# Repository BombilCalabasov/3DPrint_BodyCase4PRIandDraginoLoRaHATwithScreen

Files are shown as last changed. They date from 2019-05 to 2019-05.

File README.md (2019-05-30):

# 3DPrint_BodyCase4PRIandDraginoLoRaHATwithScreen
Files for 3D print the BodyCase for assembled RaspberryPI3 + Dragino LoRa Hat + 5" 800x480 DSI Screen

<p>There is the project for 3D print the case for assembled device from next components:</p>
<ol><li>Raspberry Pi2/3/3+</li>
<li><a href="http://www.dragino.com/products/lora/item/106-lora-gps-hat.html">Dragino LoRa&GPS Hat for Raspberry Pi</a></li>
<li><a href="https://www.aliexpress.com/item/32954192404.html?spm=a2g0s.8937460.0.0.66932e0eVrc0Jg">5 inch 800x480 TFT Touch Screen LCD Display with DSI Connector for Raspberry Pi</a></li></ol>

<p>This assembled device is very useful for any tests of LoRa technology but it's so fragile and can be damaged very easy.</p>
<p>
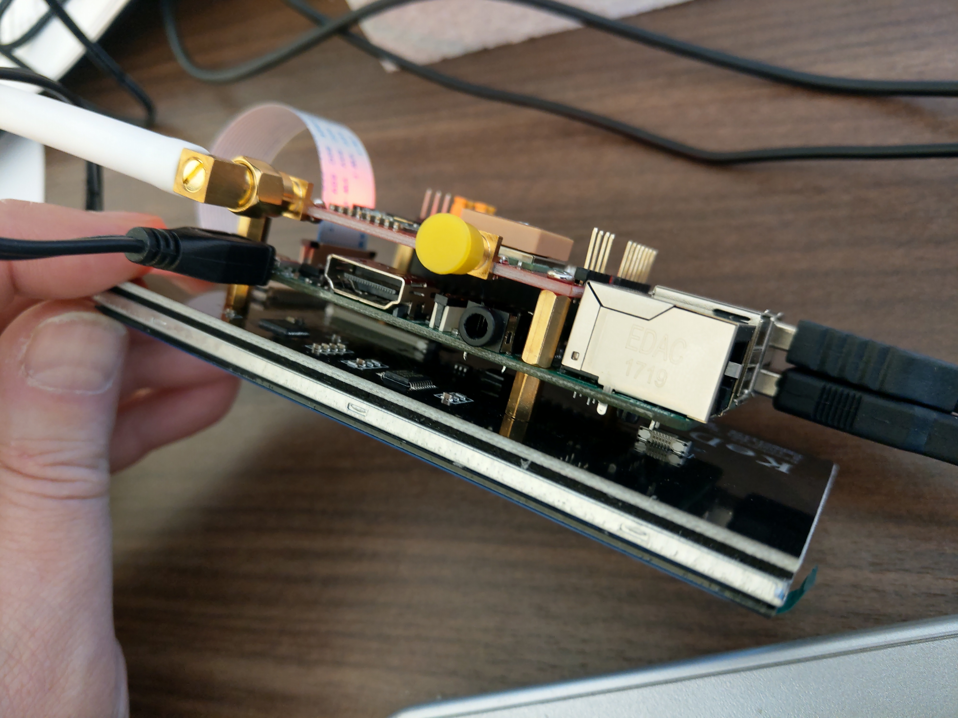
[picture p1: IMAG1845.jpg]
</br>
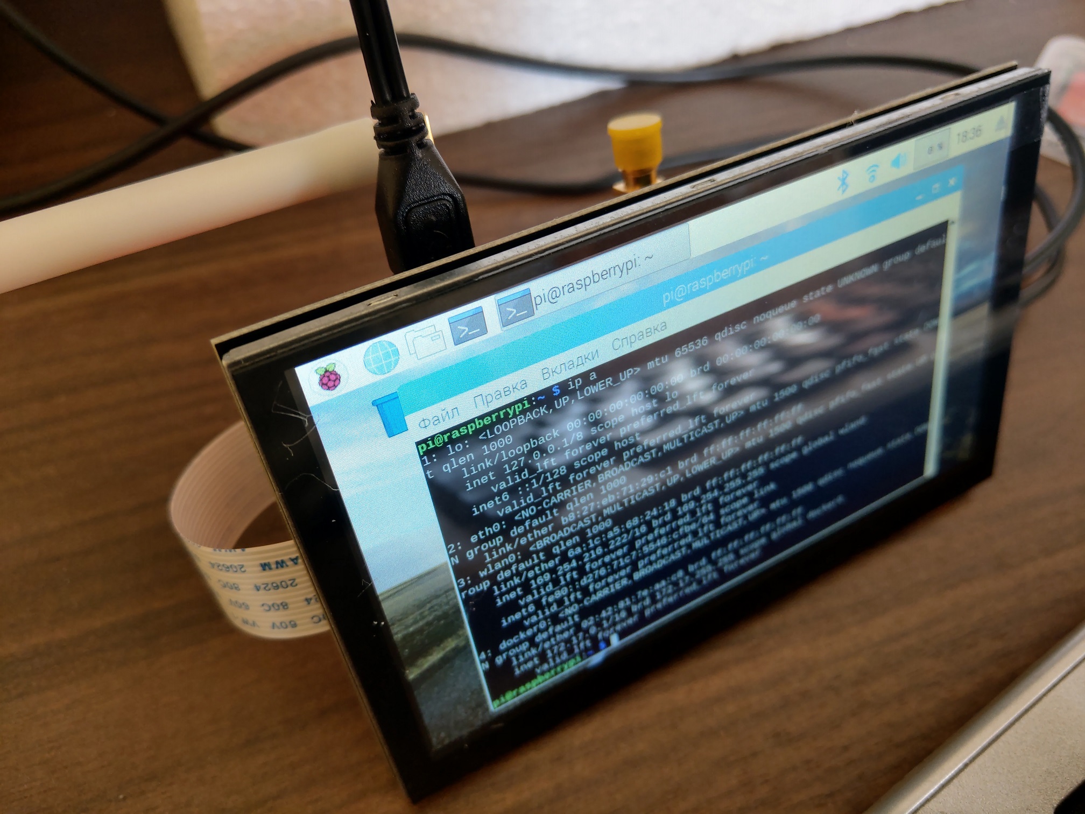
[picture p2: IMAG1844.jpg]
</br>
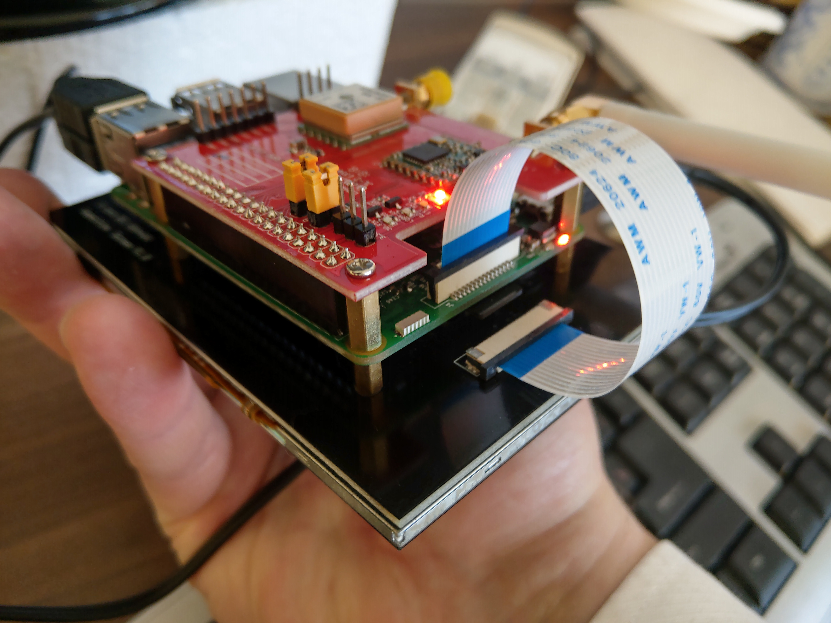
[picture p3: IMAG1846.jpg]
</br>
</p>
<h2>Modifying GPIO Connector at Dragino board</h2>
<p>First of all the Dragino board was modifyed to allow connect any additional HW (sensors and modules) to Raspberry GPIO connector without Body Case disassembling. The <a href="https://www.aliexpress.com/item/32898319378.html?spm=a2g0s.9042311.0.0.6f554c4du8pb8R">40-pins 'PC-104'-type connector</a> was used for replace original Dragino connector.</br>(N.B. Of course, you must have a good experience in soldering and proper tools to change the connector without damaging the board.)</p><p>
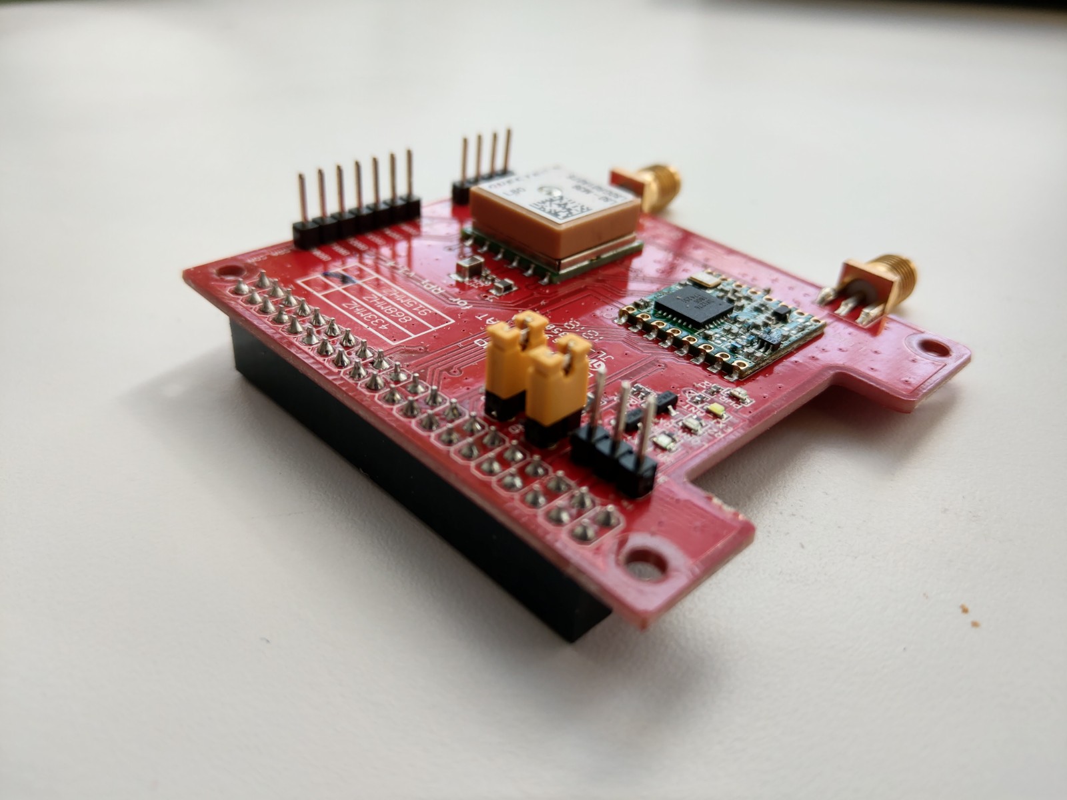
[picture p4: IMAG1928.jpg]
Original Dragino Hat</img></br></br>
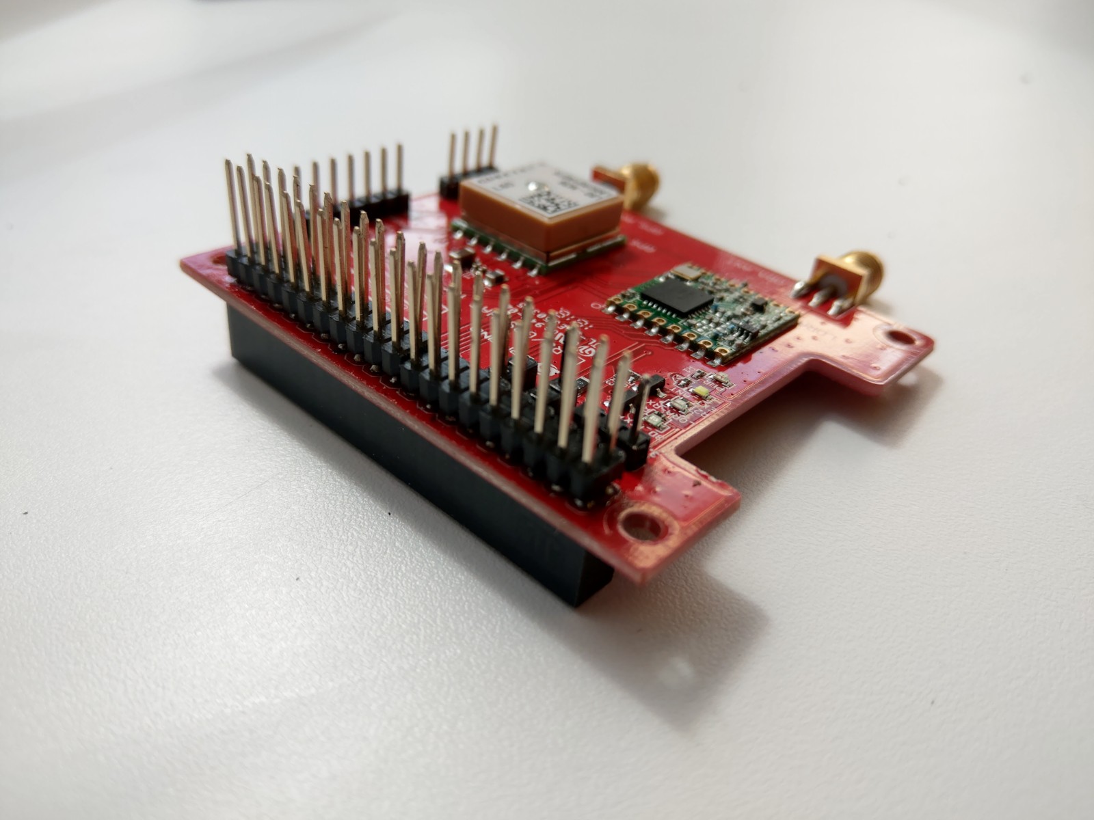
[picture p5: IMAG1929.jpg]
Modifyed Dragino Hat</img></br></br>
</p>
<h2>3D-printable Body Case</h2>
<p>To prevent possible damaging the 3D-printable case was deployed.  It contents three parts:</p>
<ol>
<li>Front panel (screen cover) -- <a href="RPi3wScreen-FrontPanel.stl">.STL</a>, <a href="RPi3wScreen-FrontPanel.zip">.OBJ(ZIP)</a></li>
<li>Body -- <a href="./PRi3wScreen-Body.stl">.STL</a>, <a href="./PRi3wScreen-Body.zip">.OBJ(ZIP)</a></li>
<li>Hat cover -- <a href="./PRi3wScreen-Hat2.stl">.STL</a>, <a href="PRi3wScreen-Hat2.zip">.OBJ(ZIP)</a></li></ol>

<h2>How to assemble</h2><ol>
  <li>Put the Screen into printed Front Panel.</li>
  <li>Install printed Body part of case. Use any four small 2mm screws to fix the Body part at Front panel.</li>
  <li>Connect DSI interface to Display.</li>
  <li>Install previously prepared SD card into SD-slot at Raspberry.</li>
  <li>Install Raspberry into Body and fix it by brass cylinders from Dragino pack.</li>
  <li>Connect DSI interface to Raspberry.</li>
  <li>Install Dragino LoRa&GPS HAT at Raspberry and fix it by four screws.</li>
  <li>Close the body of case by Hat Cover and fix it by others four small screw.</li></ol>
<p>Now your accembled device is ready for tests.</p>
<p>
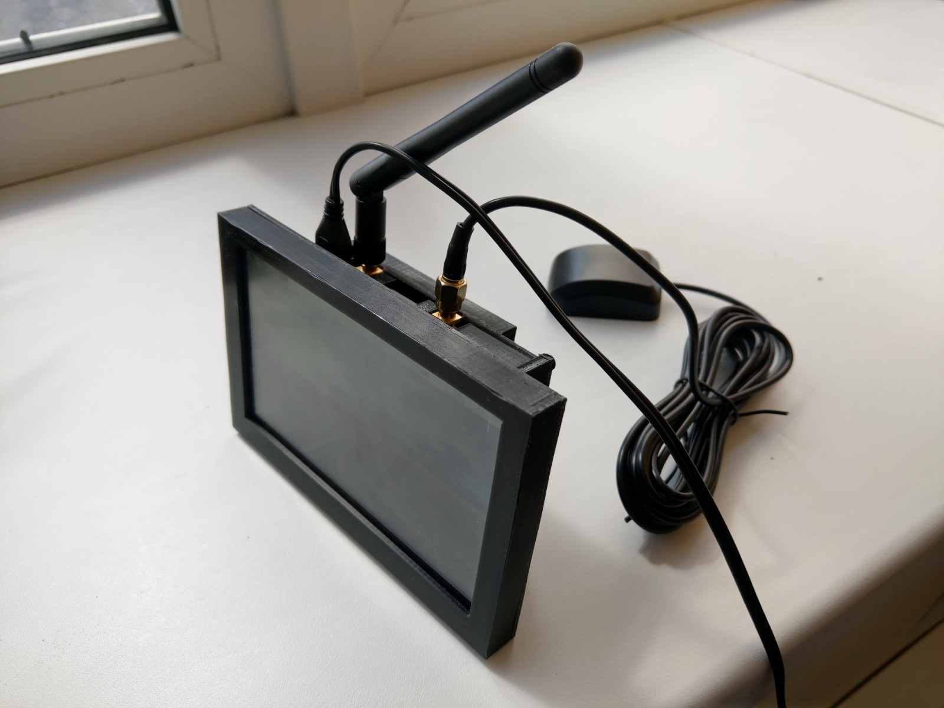
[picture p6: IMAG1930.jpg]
Assembled device</img></br></br>
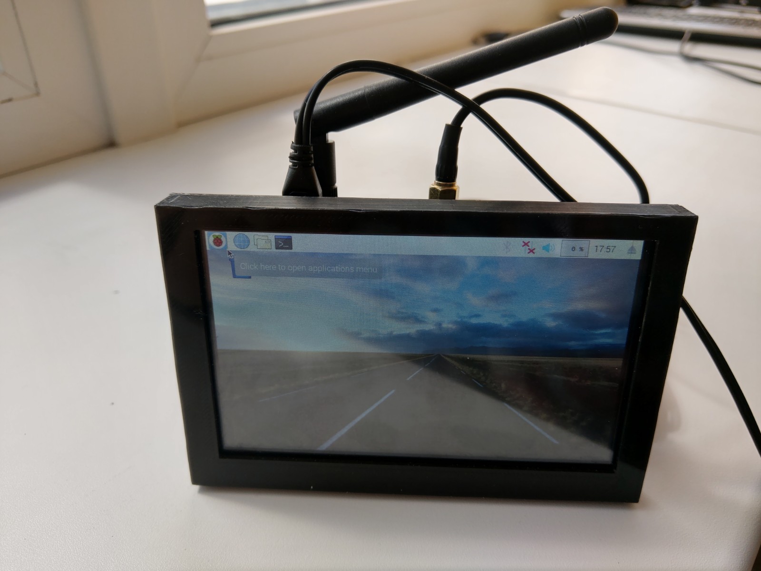
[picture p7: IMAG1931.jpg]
</br></br>
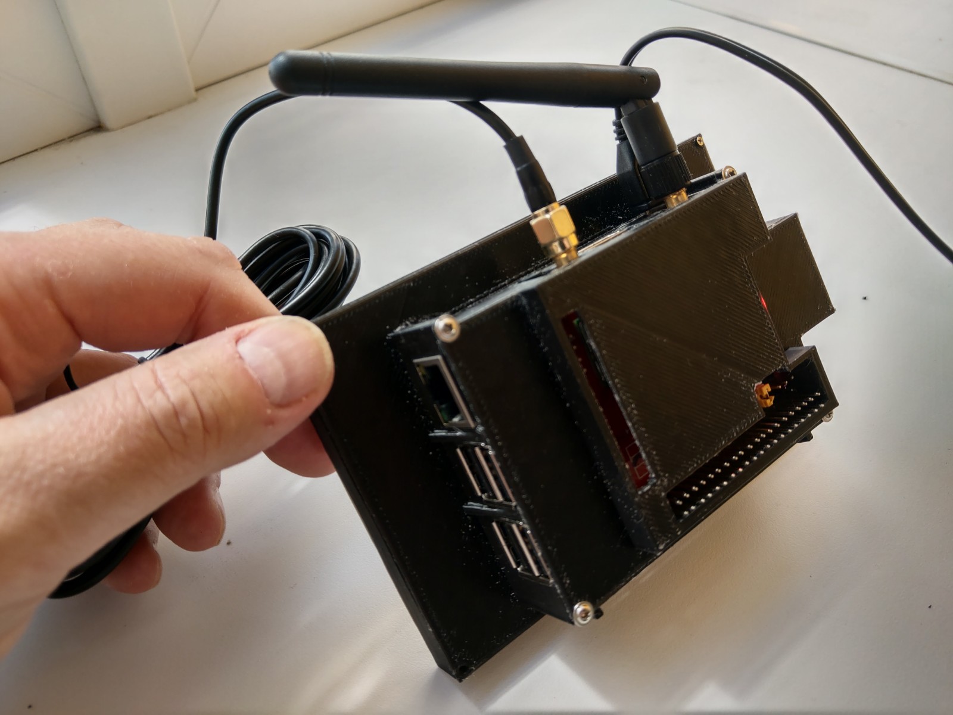
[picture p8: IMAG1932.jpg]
</br></br>
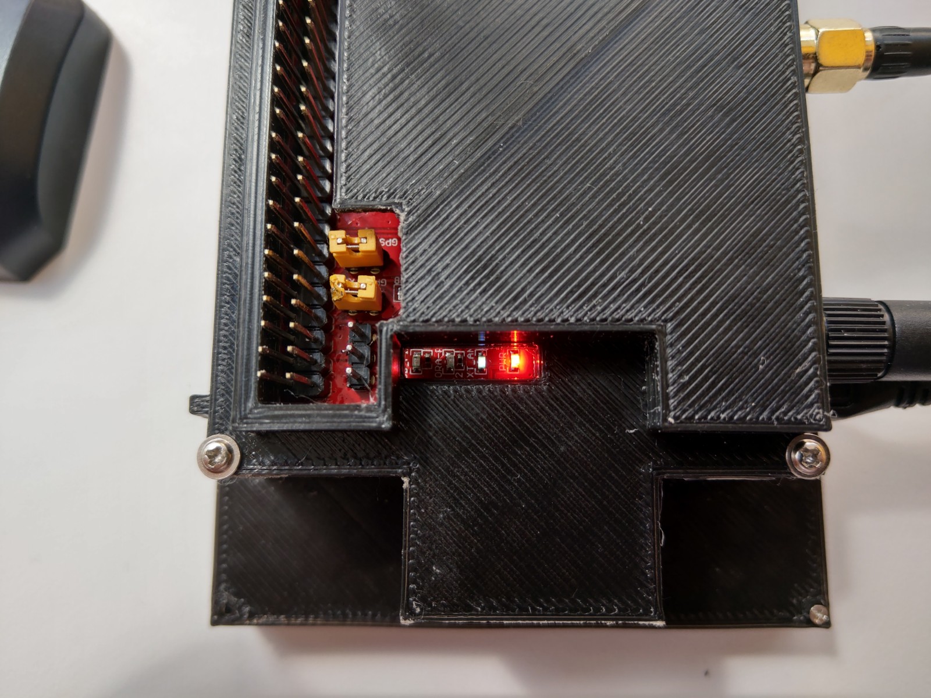
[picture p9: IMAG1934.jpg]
The Body Case has small windows for LEDs at Dragino and Raspberry boards.</img></br></br>
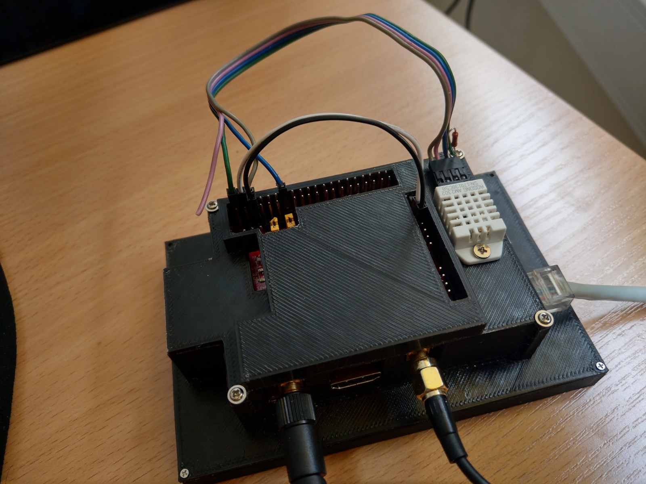
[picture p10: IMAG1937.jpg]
With this case you can easy connect any additional sensors - DHT-22 for example.</img></p>
<h2>PRO & CONS</h2>
<h3>PRO</h3>
<ul>
  <li>You can easy connect any additional sensors and modules directly to Raspberry GPIO Connector and Dragino HAT pins without disassembling Body Case.</li>
  <li>The Body Case has special holes at the bottom for air cooling. Anyway using any special radiators for Raspberry CPU is the good idea.</li>
  <li>The Body Case has special small windows to look at the LEDs state - both on Dragino and Raspberry boards.</li>
</ul>
<h3>CONS</h3><ul>
  <li>The changing the SD-card is very hard procedure with this Body Case because DSI cable covers SD-slot. To change SD-card you will be able to partially disassemble this device to grant the access to SD-card slot. Sorry, but I have no ideas how to solve this issue.</li>
  <li>Used 40pins 'PC-104' connector has the too long pins. They slightly protrude from the body cover. It's has a risk of short sircuit and damage the device. In my case it's not important because all tests are peroformed at my desktop. If this issue is important for you try to find another item with shorten pins.</li></ul>

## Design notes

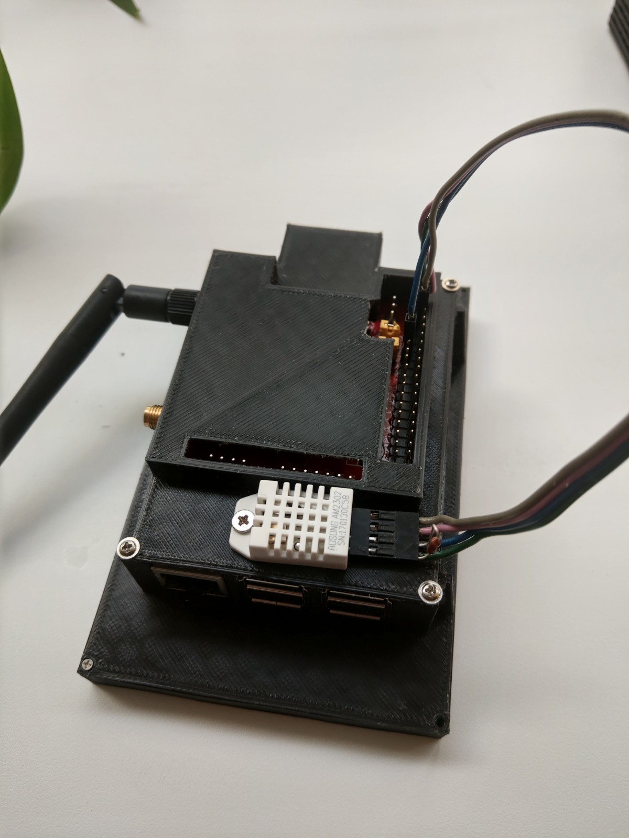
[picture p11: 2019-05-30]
IMAG1936.jpg

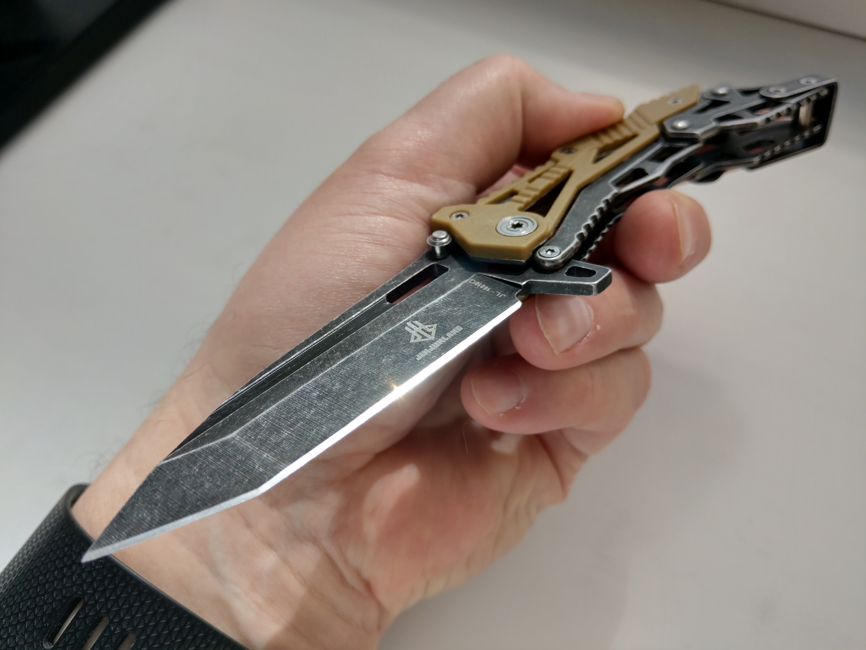
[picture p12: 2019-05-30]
IMAG1848.jpg

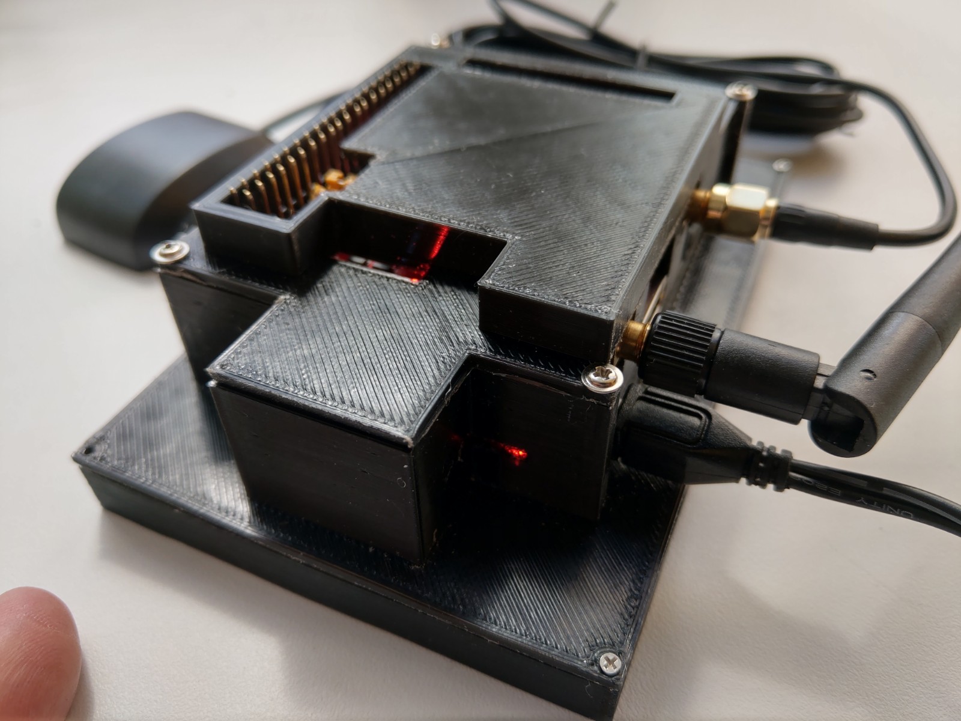
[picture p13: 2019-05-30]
IMAG1933.jpg

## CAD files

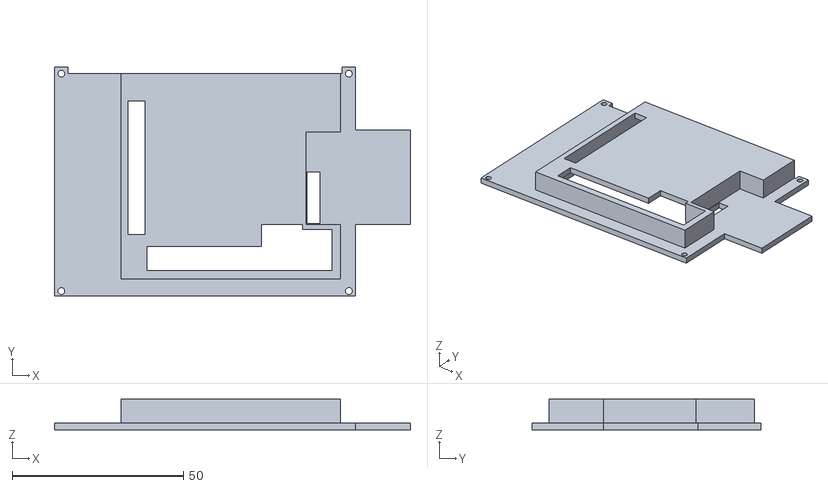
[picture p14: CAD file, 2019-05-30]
PRi3wScreen-Hat2.stl
104.0 x 67.0 x 9.00

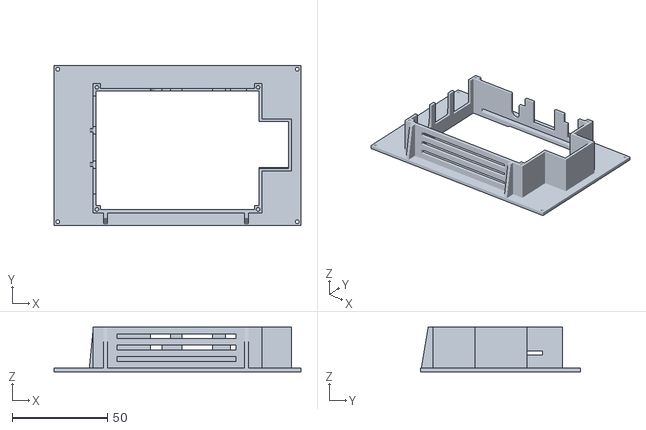
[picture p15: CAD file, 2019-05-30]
PRi3wScreen-Body.stl
129.5 x 84.0 x 23.5

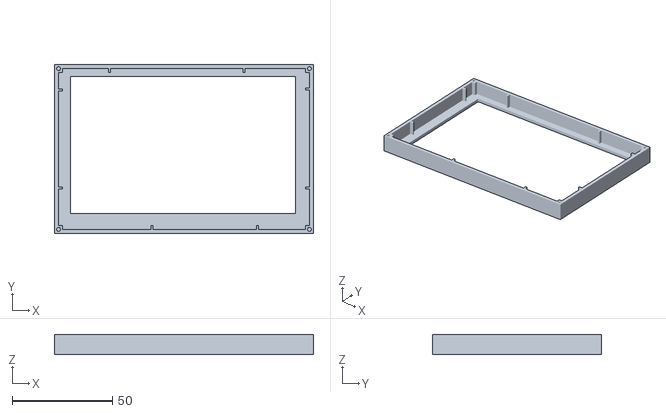
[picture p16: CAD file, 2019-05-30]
RPi3wScreen-FrontPanel.stl
129.0 x 84.0 x 10.0
